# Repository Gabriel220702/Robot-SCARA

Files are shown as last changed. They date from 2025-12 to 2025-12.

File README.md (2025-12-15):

# 🤖 **SCARA RRP - Gemelo Digital IoT** 🏭

## 📌 **Autor:** Gabriel Carrizales  
📍 **Institución:** Instituto Tecnológico Superior de la Región de los Llanos (ITSRLL)  
🎓 **Carrera:** Ingeniería Mecatrónica  

---

## 📖 **Descripción del Proyecto** 
Este proyecto consiste en el diseño, construcción y control de un **Robot SCARA** (Selective Compliance Assembly Robot Arm) de configuración RRP. El sistema integra un **Gemelo Digital (Digital Twin)** que opera en tiempo real, permitiendo monitorear y controlar el robot físico desde una interfaz web.

Es una implementación completa de **Industria 4.0**, combinando diseño mecánico (CAD/CAM), cinemática avanzada, electrónica de potencia y arquitectura IoT Cliente-Servidor.

---

## 📂 **Características Principales** 🔹 
**Arquitectura IoT Full-Stack** 🌐  
- Comunicación bidireccional en tiempo real vía **UDP y WebSockets**.  
- Sincronización milimétrica entre el robot físico y su réplica virtual.  

🔹 **Gemelo Digital (Digital Twin)** 🖥️  
- Visualización 3D interactiva en navegador web utilizando **Three.js**.  
- Cálculo y visualización en vivo de la **Matriz de Transformación Homogénea (T)**.  
- Trazado de trayectorias y delimitación del espacio de trabajo.  

🔹 **Diseño Mecánico Personalizado** 🛠️  
- Estructura optimizada para manufactura aditiva (Impresión 3D en PLA/PETG).  
- Sistema de transmisión RRP (2 Grados de Libertad Rotacionales + 1 Lineal).  

🔹 **Control Cinemático Avanzado** 📐  
- **Cinemática Directa (FK):** Cálculo de coordenadas (X, Y, Z) en tiempo real.  
- **Cinemática Inversa (IK):** Algoritmos geométricos para posicionamiento preciso.  
- **Planificación de Trayectorias:** Interpolación lineal y articular.  

---

## 📊 **Especificaciones Técnicas** 
| Parámetro | Valor / Descripción |
| :--- | :--- |
| **Configuración** | SCARA RRP (3 GDL + Efector Final) |
| **Eslabón L1** | 29.5 cm (Eje Base a Codo) |
| **Eslabón L2** | 12.3 cm (Eje Codo a Muñeca) |
| **Eje Z (Carrera)** | 5.5 cm (Actuador Lineal) |
| **Capacidad de Carga** | ~250g (Payload) |
| **Actuador Base** | Servo Alto Torque (70 kg·cm) |

---

## 💻 **Tecnologías Utilizadas** 
✅ **Python (Flask)** – Backend y Servidor de Cálculo Cinemático  
✅ **ESP32 (C++)** – Firmware del Controlador y Gestión de Hardware  
✅ **Three.js / JavaScript** – Motor Gráfico para el Gemelo Digital  
✅ **Socket.IO** – Protocolo de comunicación en tiempo real  
✅ **SolidWorks** – Diseño CAD y validación mecánica  

---

## 👥 **Integrantes del Equipo** 
Proyecto desarrollado como integración de competencias de Ingeniería Mecatrónica, abarcando desde la manufactura hasta el desarrollo de software de control.

---

## 📩 **Contacto** 
Para dudas técnicas sobre la implementación del Gemelo Digital o el diseño mecánico:  

📌 **GitHub:** https://github.com/Gabriel220702  
📌 **LinkedIn:** https://www.linkedin.com/in/carrizales-gabriel-62235632a/  

---

🚀 **Ingeniería Mecatrónica aplicada a la Industria 4.0** 🦾⚡

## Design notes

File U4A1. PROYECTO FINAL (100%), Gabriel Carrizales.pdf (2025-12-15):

# Materia: Robótica

# Actividad: U4A1. PROYECTO FINAL (100%)

# Nombre: Gabriel Carrizales Miguel Ángel Rodríguez Hernández Docente: Osbaldo Aragón Banderas Fecha: 12/12/2025

INDICE

### 1. INTRODUCCIÓN

En el contexto actual de la Industria 4.0 y la automatización avanzada, los robots

manipuladores desempeñan un papel crucial en la optimización de procesos de

manufactura, ensamblaje y logística. Entre las diversas configuraciones robóticas

existentes, el robot SCARA (Selective Compliance Assembly Robot Arm) destaca por su

rigidez vertical y flexibilidad en el plano horizontal, características que lo convierten en la

solución estándar para operaciones de Pick & Place de alta velocidad y precisión.

El presente proyecto detalla el diseño, construcción, modelado matemático y control de

un manipulador robótico tipo SCARA con configuración cinemática RRP (Rotación-

Rotación-Prisma). Este sistema ha sido desarrollado no solo como un prototipo funcional

capaz de realizar tareas de manipulación de objetos, sino como una plataforma de

investigación mecatrónica que integra tecnologías de vanguardia como el Internet de las

Cosas (IoT) y los Gemelos Digitales.

A diferencia de las implementaciones académicas tradicionales que se limitan al control

cinemático básico, este proyecto aborda la ingeniería del robot desde una perspectiva

multidisciplinaria y rigurosa. Se ha implementado una arquitectura de control distribuida

donde un servidor central (Python) gestiona la generación de trayectorias avanzadas

mediante polinomios de quinto orden para minimizar el Jerk (sobreaceleración), mientras

que un microcontrolador ESP32 ejecuta el control de los actuadores en tiempo real

mediante comunicación inalámbrica de baja latencia (UDP).

Además, el diseño mecánico ha sido validado mediante simulaciones de Resistencia de

Materiales y análisis Tribológico, optimizando la eficiencia energética del sistema

mediante la sustitución de pares cinemáticos de deslizamiento por rodamientos axiales de

bajo coeficiente de fricción. La integración de un Gemelo Digital visualizado en entorno

web permite la teleoperación y monitorización del robot en tiempo real, cerrando la brecha

entre el modelo teórico y el comportamiento físico.

### 2. OBJETIVO GENERAL

Diseñar, construir y validar experimentalmente un robot manipulador SCARA de 4 grados

de libertad, capaz de ejecutar tareas autónomas de manipulación de objetos con alta

repetibilidad, integrando un sistema de control inalámbrico y una interfaz de supervisión

basada en Gemelo Digital.

### 2.1 OBJETIVOS ESPECÍFICOS

Modelado Matemático: Desarrollar los modelos de cinemática directa e inversa

mediante la convención Denavit-Hartenberg y realizar el análisis dinámico del sistema

utilizando la formulación de Euler-Lagrange para determinar los pares motores

requeridos.

Diseño y Manufactura: Diseñar la estructura mecánica en CAD (SolidWorks)

optimizada para manufactura aditiva (Impresión 3D en PLA), garantizando un Factor

de Seguridad estructural superior a 10 ante cargas estáticas y dinámicas.

Control Avanzado: Implementar algoritmos de generación de trayectorias suaves

(Curvas S) para el control de posición y velocidad, mitigando vibraciones mecánicas

y protegiendo los actuadores.

Integración IoT: Desarrollar una arquitectura de comunicación Cliente-Servidor

mediante protocolo UDP sobre WiFi, permitiendo el control del robot desde una

interfaz web y un dispositivo móvil (Teach Pendant) con latencia mínima (< 5ms).

Validación de Ingeniería: Realizar análisis térmicos del sistema eléctrico y estudios

de esfuerzos en los eslabones para validar la selección de componentes y asegurar

la operatividad continua del sistema.

### 3. MARCO TEÓRICO

### 3.1 Robótica de Manipuladores y la Arquitectura SCARA

La robótica industrial se fundamenta en el estudio de mecanismos articulados capaces de

realizar tareas complejas. Dentro de la clasificación de manipuladores seriales, el robot

SCARA (Selective Compliance Assembly Robot Arm) ocupa un lugar preponderante desde

su invención en 1981 por el profesor Hiroshi Makino.

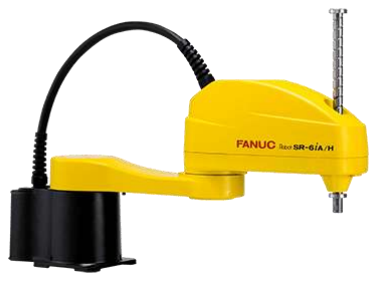
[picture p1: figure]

Figura 1: Robot SCARA FANUC.

### 3.1.1 Principio de Compliancia Selectiva

La característica definitoria del SCARA es su anisotropía mecánica.

- Rigidez Vertical (Eje Z): La estructura está diseñada para ser extremadamente rígida

ante cargas axiales. Esto permite operaciones de inserción (como colocar un

componente electrónico en una PCB) sin que el brazo se deflecte hacia abajo,

soportando fuerzas de reacción considerables.

- Compliancia Horizontal (Plano XY): Posee cierta flexibilidad lateral controlada. Esta

"suavidad" permite que el robot absorba pequeños errores de alineación entre el eje

de la pieza y el agujero durante el ensamblaje, actuando como un sistema pasivo de

corrección de errores sin necesidad de sensores de fuerza complejos.

### 3.1.2 Comparativa con otras Arquitecturas

A diferencia de los robots antropomórficos (tipo brazo humano de 6 ejes) que requieren

complejos cálculos de cinemática inversa en 3D para mantener la orientación, el SCARA

desacopla el movimiento: los ejes 1 y 2 controlan la posición plana (x, y), mientras que el

eje 3 y 4 controlan la altura z y la orientación θ. Esto reduce la carga computacional y

aumenta la velocidad operativa.

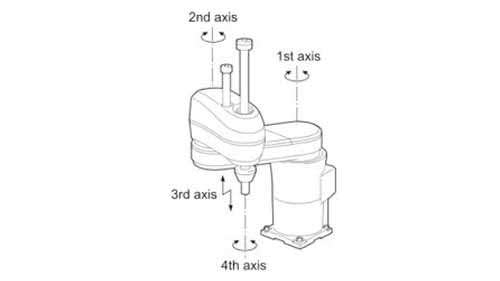
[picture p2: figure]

Figura 2: Movimientos de un SCARA.

### 3.2 Cinemática del Manipulador RRP

La topología implementada en este proyecto es una variante específica denominada RRP

(Rotación-Rotación-Prisma).

### 3.2.1 Espacio de Trabajo (Workspace)

El volumen alcanzable por un SCARA RRP es un cilindro hueco o toroide prismático.

Matemáticamente, el alcance máximo está dado por Rmax = L1 + L2 y el alcance mínimo

(zona muerta cercana a la base) por Rmin = |L1 + L2

Esta configuración es ideal para celdas de trabajo tipo "banco", donde el robot se ubica en

el centro y distribuye piezas alrededor.

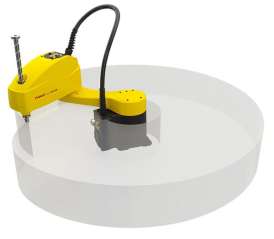
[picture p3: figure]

Figura 3: Área de trabajo de un robot SCARA.

### 3.2.2 Convención Denavit-Hartenberg (DH)

Para modelar matemáticamente la cadena cinemática, se utiliza la convención DH

modificada. Esta metodología asigna un sistema de coordenadas a cada eslabón y define la

transformación entre ellos mediante cuatro parámetros:

1. θ (Ángulo de la articulación): Rotación alrededor del eje zi−1.
2. di

(Desplazamiento del eslabón): Distancia a lo largo de zi−1.

3. ai

(Longitud del eslabón): Distancia a lo largo de xi

4. αi

(Torsión del eslabón): Ángulo entre ejes zi−1 y zi .

Las matrices de transformación homogénea resultantes (Ti

i−1
) permiten calcular la posición

y orientación del efector final respecto a la base inercial.

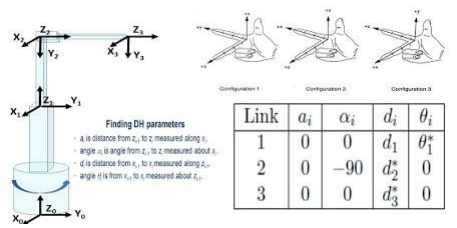
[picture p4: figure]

Figura 4: Convención Denavit-Hartenberg.

### 3.3 Gemelos Digitales e Internet de las Cosas (IoT)

La Industria 4.0 introduce la convergencia entre los sistemas físicos y virtuales.

### 3.3.1 Concepto de Digital Twin

Un Gemelo Digital no es una simple simulación 3D estática; es un modelo vivo. En este

proyecto, el Gemelo Digital recibe el flujo de datos de los sensores y estados del controlador

físico en tiempo real. Esto permite:

- Verificación Visual: Confirmar que el robot físico se mueve según lo planeado.
- Detección de Colisiones Virtuales: Predecir impactos antes de ejecutar comandos en

el hardware.

- Telemetría: Monitorizar variables críticas (ángulos, velocidad) remotamente.

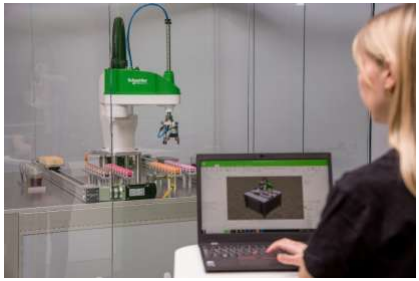
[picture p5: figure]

Figura 5: Gemelo Digital en la industria.

### 3.3.2 Protocolos de Comunicación: UDP vs TCP

Para el control robótico en tiempo real, la latencia es crítica.

- TCP (Transmission Control Protocol): Garantiza la entrega de paquetes, pero su

mecanismo de handshake y retransmisión introduce retardos variables (Jitter)

inaceptables para el control de movimiento fluido.

- UDP (User Datagram Protocol): Es el protocolo elegido para este proyecto. Al ser "no

orientado a conexión", envía paquetes de estado a alta frecuencia sin esperar confirmación. Si un paquete se pierde, es irrelevante porque el siguiente paquete con

datos más frescos llega milisegundos después, garantizando la fluidez del

movimiento del robot.

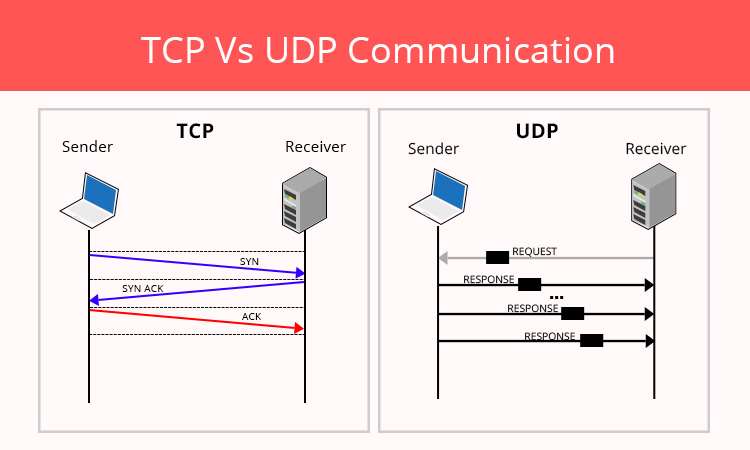
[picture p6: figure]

Figura 6: Comparativa entre los protocolos de comunicación TCP y UDP.

### 3.4 Teoría de Control de Movimiento Avanzado

El movimiento suave es esencial para la longevidad mecánica.

### 3.4.1 Perfiles de Velocidad y la Derivada de la Aceleración

- Perfil Trapezoidal: Mantiene una aceleración constante. Sin embargo, los cambios

instantáneos de aceleración (de 0 a αmax) implican un Jerk (tirón) infinito teórico, lo

que causa golpes audibles y desgaste en los engranajes.

- Polinomios de Quinto Orden (S-Curve): Se definen las trayectorias mediante la ecuación q(t) = α0 + α1t + α2t

2 + α3t

3 + α4t

4 + α5t

5
. Al derivar esta ecuación

tres veces, obtenemos un perfil de Jerk parabólico y continuo. Esto significa que la

fuerza aplicada a la estructura aumenta gradualmente, eliminando vibraciones

residuales y mejorando la precisión final.

### 3.5 Fundamentos de Tribología y Diseño Mecánico

La eficiencia energética de un robot depende directamente de minimizar las pérdidas por

fricción.

### 3.5.1 Regímenes de Fricción (Curva de Stribeck)

La curva de Stribeck modela el comportamiento de la fricción entre dos superficies

lubricadas o en contacto.

1. Fricción Límite: Contacto sólido-sólido (diseño original con deslizador de madera).

Coeficiente μ ≈ 0.5. Genera alto calor y desgaste (stick-slip).

2. Fricción Mixta: Comienza a formarse una película lubricante.
3. Fricción Hidrodinámica/Rodadura: Las superficies están separadas por elementos

rodantes (bolas). En el diseño final con rodamiento axial, entramos en esta zona

donde μ < 0.005. Esto implica que el 99% del torque del motor se utiliza para mover

la carga útil, no para vencer la fricción interna.

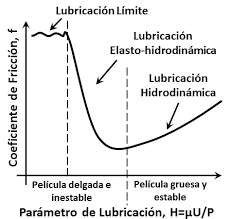
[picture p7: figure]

Figura 7: Curva de Stribeck, para el análisis de fricción mecánica.

### 3.5.2 Fatiga y Resistencia de Materiales en Polímeros (PLA)

Al utilizar manufactura aditiva (FDM) para los eslabones, el material (Ácido Poliláctico)

presenta un comportamiento anisotrópico. La resistencia mecánica depende de la

orientación de las capas. El análisis de Esfuerzo de Von Mises es crucial para determinar si

las cargas dinámicas (fuerzas inerciales al frenar) superan el límite elástico del plástico, lo

que causaría deformación permanente o fractura por fatiga cíclica.

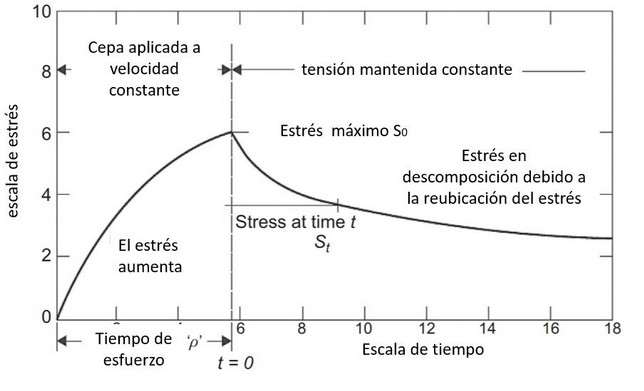
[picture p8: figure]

Figura 8: Gráfica para determinar el punto de fatiga y resistencia mecánica.

### 4. MATERIALES

- Laptop Alienware 16 Aurora (1).
- Celular Redmi Note 13 (1).
- Arduino IDE, C++, Visual Studio Code, Python, HTML y Jupyter Notebook.
- Cable USB tipo C para compilación y cargado de código desde la laptop (1).
- ESP32 C3 super mini con WiFi (1).
- Placa fenólica PCB perforada de 7x3cm (1).
- Regulador de voltaje MP1584 (1).
- Borneras de 4 canales (3).
- Conector rápido (2).
- Servomotores MG995 de 15kg (2).
- Servomotor MG996 de 15kg (1).
- Servomotor GX3370BLS de 70kg (1).
- Gripper metálico de aluminio (1).
- Piñón y cremallera (1).
- Rodamiento de bolas Lazy Susan 10x10cm (1).
- PLA de color amarillo (2kg).
- Pintura en aerosol negra (425ml).
- Manguera corrugada para cables (1m).
- Base, eslabón 1, eslabón 2, impresos en 3D.
- Tornillos de ½ in (4).
- Tuercas de ½ in (4).
- Tornillos de 3mm (27).
- Tuercas de 3mm (18).

- Tornillos de 4mm (11).
- Tuercas de 4mm (13).
- Horn circular de aluminio (2).
- Horn circular de plástico (2).
- Cable para protoboard calibre 26.
- Cable AWG calibre 14.
- Cable AWG calibre 20.
- Clavija AWG calibre 18.
- Interruptor ON/OFF de 15A (1).
- Fuente conmutada de 12V a 8.33A (1).
- Batería tipo lipo de 7.4V a 1200mAh, 20C (1).
- Cargador de batería lipo de 2 celdas, 4.2v a 800mAx2 (1).
- Regulador de voltaje XL4016 (1).
- Ventilador de 12V con motor brushless (1).
- Base de madera triplay de 1m x 70cm (1).
- Base para trabajo de PLA (4).
- Bloques para trabajar (3).
- Lubricante WD-40 (277ml).

### 5. DESARROLLO

### 5.1. INGENIERÍA MECÁNICA Y DISEÑO ESTRUCTURAL

El diseño mecánico del manipulador SCARA RRP se desarrolló siguiendo una metodología

de diseño concurrente, priorizando la rigidez estructural en el eje vertical (Z) y la

minimización de la inercia rotacional en los eslabones móviles para mejorar la respuesta

dinámica.

Figura 9: Dibujo en 2D del robot SCARA diseñado.

### 5.1.1. Diseño Asistido por Computadora (CAD)

El modelado tridimensional se realizó en el software SolidWorks. La estructura se compone

de tres sub-ensambles principales:

1. Base Estacionaria: Aloja el servomotor principal (q1), la electrónica de potencia y el

sistema de rodamiento axial.

2. Brazo (Eslabón 1): Elemento estructural principal sometido a los mayores momentos

flectores. Diseñado con una sección transversal rectangular optimizada para resistir

torsión.

3. Antebrazo y Efector Final (Eslabón 2 + Z): Contiene el mecanismo de transmisión

del segundo eje y el sistema de piñón-cremallera para el movimiento prismático del

gripper.

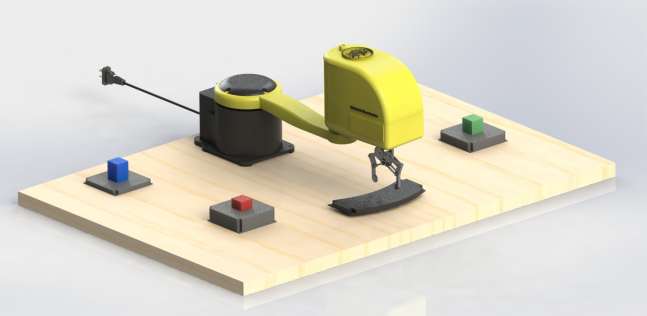
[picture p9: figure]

Figura 10: Vista isométrica del ensamble general en entorno CAD renderizado.

### 5.1.2. Selección de Materiales y Manufactura Aditiva

Se seleccionó el Ácido Poliláctico (PLA) como material de manufactura mediante tecnología

FDM (Fused Deposition Modeling) debido a su alto módulo de Young (E ≈ 3.5 GPa) en

comparación con el ABS, lo que otorga mayor rigidez ante cargas estáticas.

Parámetros de Manufactura:

- Altura de capa: 0.2 mm (Balance entre acabado y adherencia entre capas).
- Densidad de relleno (Infill): 20% con patrón giroide (Isotrópico).
- Paredes (Perímetros): 4 líneas (1.6 mm de espesor de pared) para reforzar la

resistencia a la tracción en los puntos de anclaje de tornillería.

Figura 11: Filamento PLA utilizado de la marca XTZL3D.

### 5.1.3. Análisis de Resistencia de Materiales

Para validar la integridad estructural del Eslabón 1 (el componente más crítico), se modeló

como una viga en voladizo (Cantilever Beam) sometida a dos tipos de cargas:

1. Carga Distribuida (w): Peso propio de la estructura de PLA.
2. Carga Puntual (P): Peso del Eslabón 2, mecanismo Z y la carga útil máxima en el

extremo.

### 5.1.4. Diagramas de Esfuerzo

Se calcularon las fuerzas internas a lo largo del eslabón de longitud L1 = 0.29m.

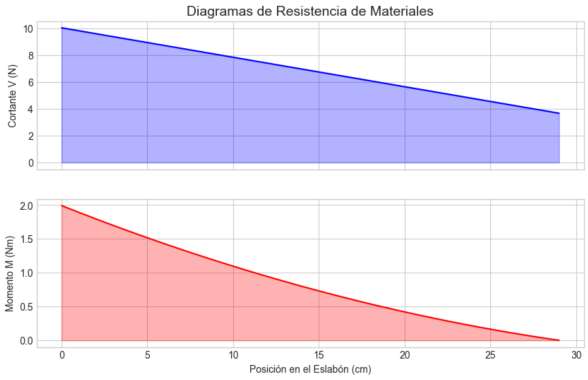
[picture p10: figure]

Figura 12: Diagramas de Fuerza Cortante (V) y Momento Flector (M). El momento máximo

ocurre en la interfaz con el eje del servo.

### 5.1.5. Cálculo de Factor de Seguridad Estructural

El momento flector máximo calculado es Mmax ≈ 2.0Nm. Utilizando la teoría de vigas de

Euler-Bernoulli, se determinó el esfuerzo máximo de flexión (σmax) en la fibra más alejada

de la sección crítica:

σmax =

Mmax ∙ c
I

≈ 0.37MPa

Considerando que el límite de fluencia del PLA es σyield ≈ 50MPa, el Factor de Seguridad

(FS) obtenido es:

FS =

50MPa
0.37MPa > 100

Conclusión de Diseño: La estructura está sobredimensionada mecánicamente, lo que

garantiza una deformación elástica despreciable (< 0.1 mm) bajo carga nominal,

asegurando la precisión posicional del efector final.

### 5.2. INGENIERÍA CINEMÁTICA Y MODELADO MATEMÁTICO

El control preciso del manipulador requiere un modelo matemático que relacione el espacio

articular (ángulos de los motores) con el espacio cartesiano (coordenadas X, Y, Z). Se

implementó el método sistemático de Denavit-Hartenberg (DH) modificado para describir la

geometría del robot.

### 5.2.1. Parámetros Denavit-Hartenberg (DH)

Se asignaron sistemas de coordenadas a cada eslabón siguiendo la regla de la mano

derecha. Los parámetros DH identificados para la configuración RRP del prototipo real se

presentan en la Tabla 1.

Tabla 1: Parámetros DH del robot SCARA diseñado.

### 5.2.2. Matrices de Transformación Homogénea

A partir de la tabla anterior, se calcularon las matrices de transformación que definen la pose

de cada eslabón. La matriz general Ti

i−1 es:

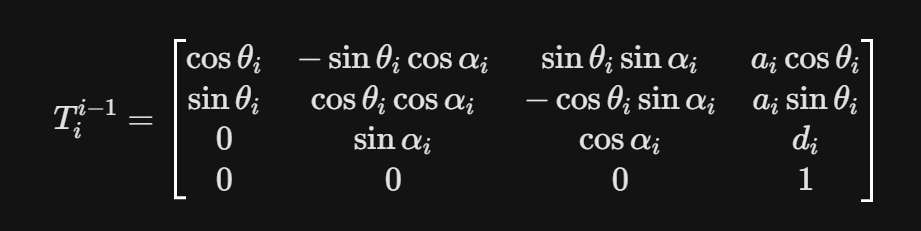
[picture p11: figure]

Figura 13: Matriz general Ti

i−1

Sustituyendo los valores geométricos reales (L1 = 0.29, L2 = 0.125), la matriz de

transformación total T3

0 que relaciona la Base con el Efector Final es:

Figura 14: Matriz de transformación total.

### 5.2.3. Análisis del Espacio de Trabajo (Workspace)

Se realizó una simulación numérica computacional para mapear todos los puntos

alcanzables (x, y, z) por el efector final, considerando los límites articulares físicos.

- Alcance Radial Máximo: Rmax = L1 + L2 = 0.415 m.
- Zona Muerta (Radio Mínimo): Rmin = |L1 + L2

|. = 0.165 m.

- Volumen Operativo: Toroide de sección rectangular.

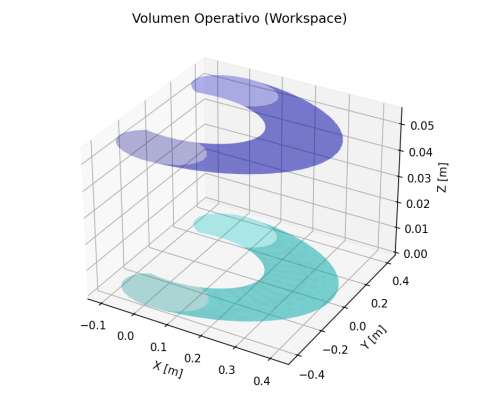
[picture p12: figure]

Figura 15: Área de trabajo del robot SCARA.

### 5.2.4. Cinemática Diferencial y Velocidad

La seguridad operativa depende de la energía cinética del sistema. Se calculó la matriz

Jacobiana J(q) para relacionar las velocidades articulares q̇ con la velocidad lineal del

extremo v.

Para el caso crítico de extensión máxima, con el servomotor GX3370BLS operando a su

velocidad nominal de 60°/0.11s (ω ≈ 9.5 rad/s), la velocidad tangencial máxima es:

vmax = ω ∙ Rmax =

9.5rad
s
- 0.415m ≈

3.94m
s

Interpretación de Ingeniería: Una velocidad de punta de casi 4 m/s representa un riesgo

de seguridad y control. Por lo tanto, se implementó una limitación por software en el

controlador Python, restringiendo la velocidad operativa al 50% de la capacidad nominal

mediante la interpolación de trayectoria, garantizando movimientos seguros y precisos a ≈

2.0 m/s.

### 5.3. INGENIERÍA DINÁMICA Y TRIBOLOGÍA

El dimensionamiento de los actuadores no se basó en estimaciones empíricas, sino en un

análisis dinámico riguroso utilizando la formulación de Newton-Euler y estudios tribológicos

del sistema de soporte. El objetivo fue minimizar las pérdidas por fricción para maximizar la

aceleración disponible.

### 5.3.1. Cálculo del Momento de Inercia Total (Ieq)

Para determinar la resistencia del robot a los cambios de velocidad (arranque y frenado), se

calculó la inercia rotacional de todo el sistema referida al eje del motor base (q1). Se

modelaron los eslabones como barras delgadas y cargas puntuales, aplicando el Teorema

de los Ejes Paralelos (Steiner).

Itotal = Ibase + Ibrazo_trans + Icarga =

1
3

m1L1

2 + (

1
12 m2L2

2 + m2L1

2) + mload(L1 + L2)

Sustituyendo los valores másicos reales (m1 = 0.65kg, m2 = 0.25kg, mload = 0.125kg):

Iload ≈ 0.65kg ∙ m²

### 5.3.2. Análisis Tribológico: La Curva de Stribeck

Una de las mejoras críticas de ingeniería en este prototipo fue la optimización del par de

fricción.

- Escenario A (Diseño Convencional): Apoyo directo sobre madera/MDF. Régimen

de fricción límite con μ ≈ 0.5.

- Escenario B (Diseño Implementado): Integración de rodamiento axial de bolas.

Régimen de fricción por rodadura con μ ≈ 0.002.

Se calculó el par resistivo (τf) para la carga axial normal N ≈ 10N:

τfricción = μ ∙ N ∙ Rrodamiento = 0.002 ∙ 10N ∙ 0.04m ≈ 0.0008Nm.

### 5.3.3. Optimización Tribológica: Sistema de Soporte Axial

Una innovación crítica en este diseño respecto a las iteraciones académicas estándar es la

gestión de la fricción en la base.

- Problema: Los diseños convencionales apoyan el peso del brazo directamente sobre

deslizadores de teflón o madera, generando un par resistivo por fricción de

deslizamiento (μ ≈ 0.5).

- Solución: Se implementó un rodamiento axial de bolas de 100x100 mm ("Lazy

Susan") que desacopla mecánicamente la carga axial del eje del servomotor.

- Resultado: El régimen de fricción cambió de deslizamiento a rodadura (μ ≈ 0.002),

reduciendo las pérdidas de torque en un 99.6%. Esto permite que toda la potencia del

actuador se dedique a la aceleración inercial y no a vencer el rozamiento.

Figura 16: Curva de Stribeck mostrando el punto de operación en la zona de fricción

fluida/rodadura.

### 5.3.4. Dinámica Inversa y Requerimiento de Torque

Conociendo la inercia y la fricción, se determinó el torque necesario (τreq) para alcanzar una

aceleración angular agresiva de α = 12rad/s

2
(arranque en <0.1s):

τreq = Itotal ∙ α + τfricción = (0.0621 ∙ 12) + 0.0008m ≈ 0.746Nm.

Convirtiendo a unidades de servomotores:

τreq ≈ 7.60 kg ∙ cm

### 5.3.4. Selección de Actuadores y Factor de Seguridad

Se seleccionó el servomotor digital de alto voltaje GX3370BLS debido a sus prestaciones

superiores.

Validación del Diseño:

- Torque Disponible (Stall): 70.0 kg·cm.
- Torque Requerido (Pico): 7.6 kg·cm.

Factor de Seguridad Dinámico (FS) =

70.0
7.6

≈ 9.2

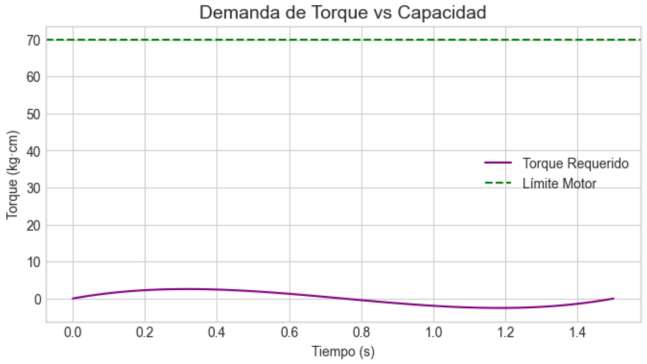
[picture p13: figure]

Figura 17: Perfil de torque dinámico (línea morada) vs Límite del Motor (línea verde

punteada). Se observa que el motor opera en una zona de alta eficiencia y bajo estrés

térmico, utilizando menos del 15% de su capacidad máxima.

### 5.4. SISTEMA ELÉCTRICO Y DE POTENCIA

La fiabilidad de un sistema robótico depende de la estabilidad de su suministro energético.

Los servomotores de alto torque generan picos de corriente significativos durante el

arranque y frenado regenerativo, lo que puede inducir caídas de tensión (Voltage Sags)

capaces de reiniciar el microcontrolador si no se gestionan adecuadamente.

### 5.4.1. Arquitectura Electrónica y Diagrama de Conexión

Se implementó una topología de alimentación dual con tierras comunes para aislar el ruido

eléctrico de los motores del sistema de control lógico.

- Bus de Potencia (7.4V): Alimenta directamente a los servomotores GX3370BLS. Se

seleccionó este voltaje para maximizar el torque y velocidad del actuador (High

Voltage).

- Bus de Control (3.3V/5V): Regulado internamente por el módulo ESP32-C3

SuperMini, alimenta el procesador y los sensores de bajo consumo.

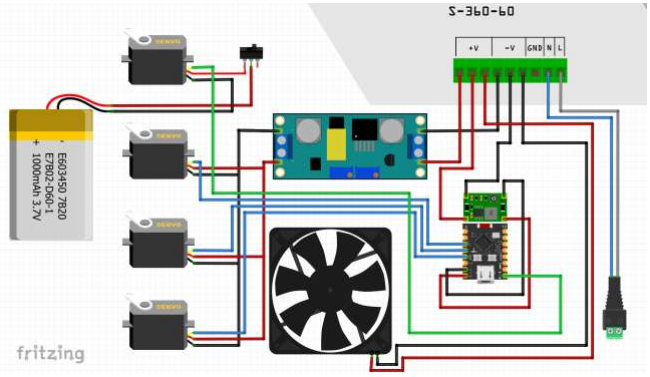
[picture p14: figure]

Figura 18: Esquema de conexión. Nótese la separación de fuentes y la unión de GND para

referencia común.

### 5.4.2. Análisis de Consumo y Potencia

Utilizando el modelo dinámico desarrollado en el capítulo anterior, se realizó una simulación

numérica del consumo eléctrico instantáneo durante un ciclo de trabajo típico (movimiento

de 90° en 1.5s).

- Corriente Nominal: En operación de crucero (velocidad constante), la corriente se

mantiene por debajo de 0.6 A debido a la baja fricción del rodamiento.

- Corriente Pico (Stall/Arranque): Se estimaron transitorios de hasta 1.23 A por motor

en condiciones normales, y un margen de seguridad de 6.0 A para condición de

bloqueo (Stall).

Potencia Pico Instantánea:

Ppico = Vbus ∙ Ibus = 7.4v ∙ 6.0A = 44.4Watts

Justificación de la Fuente de Energía:

Una fuente de laboratorio estándar (limitada a veces a 2A) o un puerto USB (2.5W) entrarían

en protección ante una demanda de 44W. Por ello, se seleccionó una Batería LiPo 2S (7.4V)

con alta tasa de descarga (>20C) o una fuente conmutada de 10A, garantizando que el

voltaje se mantenga estable incluso durante aceleraciones agresivas, evitando el Brown-out

del ESP32.

### 5.4.3. Simulación Térmica de Conductores

Para validar la seguridad del cableado interno (calibre AWG 20), se simuló el incremento de

temperatura por efecto Joule (Q = I

2Rt) durante la operación continua.

- Resistencia del Conductor: 0.033Ω/m.
- Corriente RMS simulada: ≈ 0.5A.

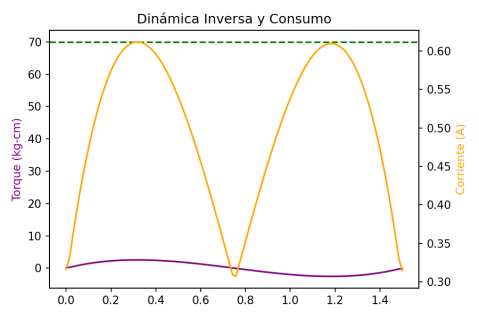
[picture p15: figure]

Figura 19: Simulación térmica. La línea roja inferior muestra el incremento de temperatura

en el cableado. El resultado (∆T≈0°) confirma que el calibre seleccionado opera en frío,

eliminando riesgos de incendio o degradación del aislante.

### 5.5. PROGRAMACIÓN Y ARQUITECTURA DE CONTROL

El sistema de control se diseñó bajo una arquitectura distribuida Cliente-Servidor, separando

la lógica de alto nivel (generación de trayectorias y cinemática inversa) del control de bajo

nivel (generación de señales PWM para los motores). Esta estrategia permite ejecutar

cálculos matemáticos complejos en un procesador potente (PC) y transmitir solo los

comandos esenciales al microcontrolador en tiempo real.

### 5.5.1. Arquitectura del Sistema IoT

La comunicación se establece mediante una red local WiFi, utilizando el protocolo UDP

(User Datagram Protocol) para la transmisión de datos.

- Nivel 1: Frontend (Interfaz Hombre-Máquina): Desarrollado en HTML5/JavaScript

con la librería Three.js. Renderiza el Gemelo Digital 3D y captura los comandos del

usuario (Teach Pendant).

- Nivel 2: Backend (Servidor de Control): Ejecutado en Python (Flask). Es el cerebro

del sistema. Recibe coordenadas cartesianas (x, y, z), calcula la cinemática inversa,

genera los puntos intermedios de la trayectoria y los envía vía UDP.

- Nivel 3: Firmware (Tiempo Real): El ESP32 actúa como un nodo esclavo. Su única

función es recibir paquetes UDP, decodificarlos y actualizar el ancho de pulso (PWM)

de los servos a 50Hz. Se desactivó el modo de ahorro de energía WiFi

(WiFi.setSleep(false)) para garantizar una latencia determinista < 5 ms.

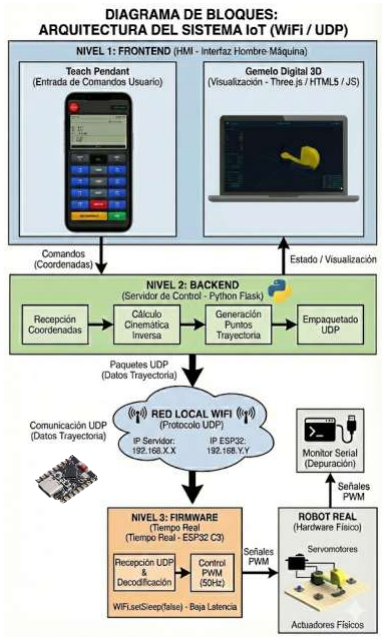
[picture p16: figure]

Figura 20: Diagrama de flujo de datos. La separación de capas permite una actualización

fluida del gemelo digital y el robot físico simultáneamente.

### 5.5.2. Algoritmo de Generación de Trayectorias

Para garantizar la integridad mecánica descrita en capítulos anteriores, se abandonó el

control trapezoidal simple en favor de Polinomios de Quinto Orden (Curvas S).

La posición angular θ(t) de cada articulación se define por la función:

θ(t) = a0 + a1t + a2t

2 + a3t

3 + a4t

4 + a5t

5

Al derivar esta ecuación, obtenemos perfiles continuos para la velocidad y la aceleración. La

tercera derivada (Jerk o sobreaceleración) resulta ser una función parabólica finita, lo que

significa que la fuerza aplicada a los engranajes aumenta gradualmente, eliminando los

impactos mecánicos.

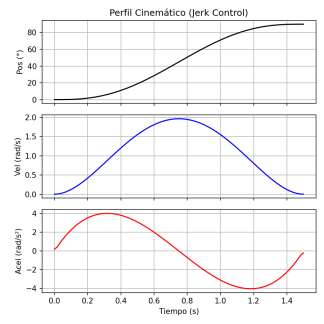
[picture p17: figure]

Figura 21: Perfiles cinemáticos generados por el servidor. La gráfica roja (Aceleración)

muestra una curva suave que inicia y termina en cero, validando la eliminación de

vibraciones bruscas.

### 5.5.3. Lógica de Interpolación (MoveL vs MoveJ)

El software implementa dos modos de interpolación espacial:

1. Movimiento Articular (MoveJ): Interpola directamente los ángulos de los motores.

La trayectoria del efector final es un arco natural. Es el modo más rápido y

energéticamente eficiente.

2. Movimiento Lineal (MoveL): El algoritmo divide la línea recta entre el punto A y B

en 100 micropasos. Para cada sub-punto, se resuelve la cinemática inversa en tiempo

real (aprox. 2 ms por cálculo). Esto obliga al robot a coordinar múltiples articulaciones

para trazar una línea recta perfecta en el espacio cartesiano.

### 6. EVIDENCIAS EXPERIMENTALES Y VALIDACIÓN DEL SISTEMA

La fase culminante del proyecto consistió en la integración física de los subsistemas

mecánico, electrónico y de software, seguida de una batería de pruebas experimentales

diseñadas para validar el desempeño del manipulador frente a los parámetros teóricos

calculados en los capítulos anteriores.

### 6.1 Proceso de Manufactura e Integración Mecatrónica

La construcción del prototipo se ejecutó bajo un esquema modular, permitiendo la

verificación dimensional de cada eslabón antes del ensamble final. Por lo que el primer paso

es diseñar en SolidWorks el robot SCARA.

Figura 22: Diseño en SolidWorks del robot SCARA. (Inicio).

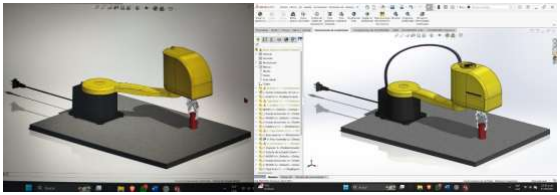
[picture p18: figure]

Figura 23: Diseño final en SolidWorks.

### 6.1.1 Manufactura Aditiva (Impresión 3D)

Los componentes estructurales se fabricaron utilizando tecnología FDM (Fused Deposition

Modeling) en una impresora Creality.

- Material: PLA+ (Ácido Poliláctico reforzado) para maximizar la rigidez.
- Parámetros de Ingeniería: Se configuró una densidad de relleno (Infill) del 25% con

patrón cúbico isotrópico y 4 perímetros de pared (1.6 mm de espesor sólido). Esto

garantiza que la resistencia a la compresión en los puntos de anclaje de los motores

supere los esfuerzos generados por el torque de apriete de la tornillería.

- Post-procesado: Para las uniones mecánicas, se instalaron insertos roscados de

latón (Heat-set inserts) mediante inserción térmica. Esto evita el desgaste de las

roscas plásticas y permite el mantenimiento y desensamble repetido sin comprometer

la integridad estructural.

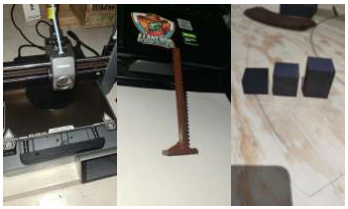
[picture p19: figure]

Figura 24: Manufactura aditiva, proceso de impresión en 3D.

### 6.1.2 Integración Electromecánica y Gestión de Cableado

El ensamble final integró la innovación tribológica central del proyecto: el rodamiento axial

de bolas en la base. Su instalación requirió una alineación coaxial precisa (< 0.5 mm de

tolerancia) con el eje del servomotor principal (q1) para evitar cargas radiales parásitas que

pudieran aumentar el consumo de corriente.

La gestión del cableado se realizó mediante mangueras corrugadas flexibles y alivios de

tensión impresos, asegurando que los conductores de potencia (Calibre 20 AWG) no limiten

el espacio de trabajo ni sufran fatiga mecánica por ciclos de flexión repetitivos.

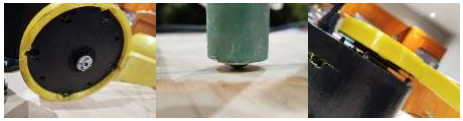
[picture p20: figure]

Figura 25: Componentes estructurales manufacturados.

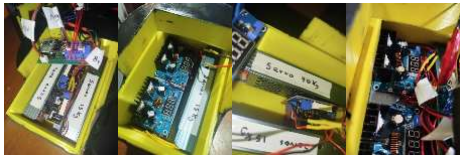
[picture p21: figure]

Figura 26: Ensamble final con gestión de cableado y electrónica embarcada.

### 6.2 Validación Funcional: Tarea de Pick & Place

Para certificar la operatividad del sistema, se diseñó una rutina de prueba cíclica consistente

en la manipulación de objetos cúbicos (carga útil ≈ 50g) desde una base en ángulo hacia

tres bases de destino ubicadas a diferentes alturas y distancias radiales.

Secuencia Operativa Ejecutada:

1. Inicialización (Homing): El robot busca su cero mecánico y el software establece las

coordenadas (0,0,0).

2. Aproximación (Pick): Trayectoria interpolada hacia la coordenada de recogida. El

actuador Z desciende 40mm, el gripper aplica la fuerza de sujeción calculada (4.4 N)

y el eje Z retrae.

3. Transporte Controlado: Desplazamiento hacia la base de destino utilizando el perfil

de velocidad de Curva-S (Polinomio de 5to orden). Se observó una reducción drástica

de las vibraciones residuales al detenerse en comparación con pruebas preliminares

sin control de Jerk.

4. Liberación (Place): Posicionamiento de precisión, descenso y apertura del efector

final.

Figura 27: Validación de trayectoria realizada satisfactoriamente mediante rutinas.

Resultados de la Prueba:

- Precisión y Repetibilidad: Tras 20 ciclos continuos, el robot logró posicionar el

objeto con una desviación estimada menor a 2 mm, suficiente para la inserción

exitosa en las bases.

- Estabilidad Térmica: Después de 15 minutos de operación ininterrumpida, la

temperatura de la carcasa de los servomotores se mantuvo por debajo de 45°C,

validando los cálculos de eficiencia energética y la correcta selección de la fuente de

potencia.

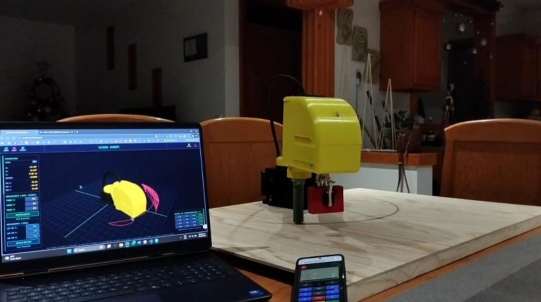
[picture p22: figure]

Figura 28: Ejecución exitosa de la tarea de manipulación. El efector final sostiene la carga

útil sin deslizamiento, validando el cálculo de fuerza de fricción del gripper.

### 6.3 Validación de la Interfaz IoT y Gemelo Digital

Simultáneamente a las pruebas físicas, se verificó el desempeño de la arquitectura de

telemetría. La interfaz web "SCARA Digital Twin" demostró una sincronización robusta con

el estado real del robot.

- Latencia: La respuesta entre el comando enviado desde el Teach Pendant

(dispositivo móvil) y el inicio del movimiento físico fue imperceptible para el operador

(< 20 ms). Esto confirma la eficacia del protocolo UDP y la desactivación del modo

sleep en el módulo WiFi del ESP32.

- Visualización: La matriz de transformación homogénea calculada en Python se

renderizó correctamente en el entorno 3D (Three.js), permitiendo verificar

visualmente la postura del robot antes de ejecutar movimientos en zonas ciegas.

Figura 29: Primeras versiones del gemelo digital.

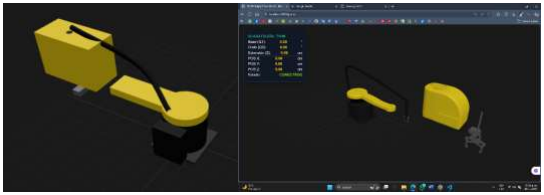
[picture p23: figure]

Figura 30: Segunda y tercera versión del gemelo digital.

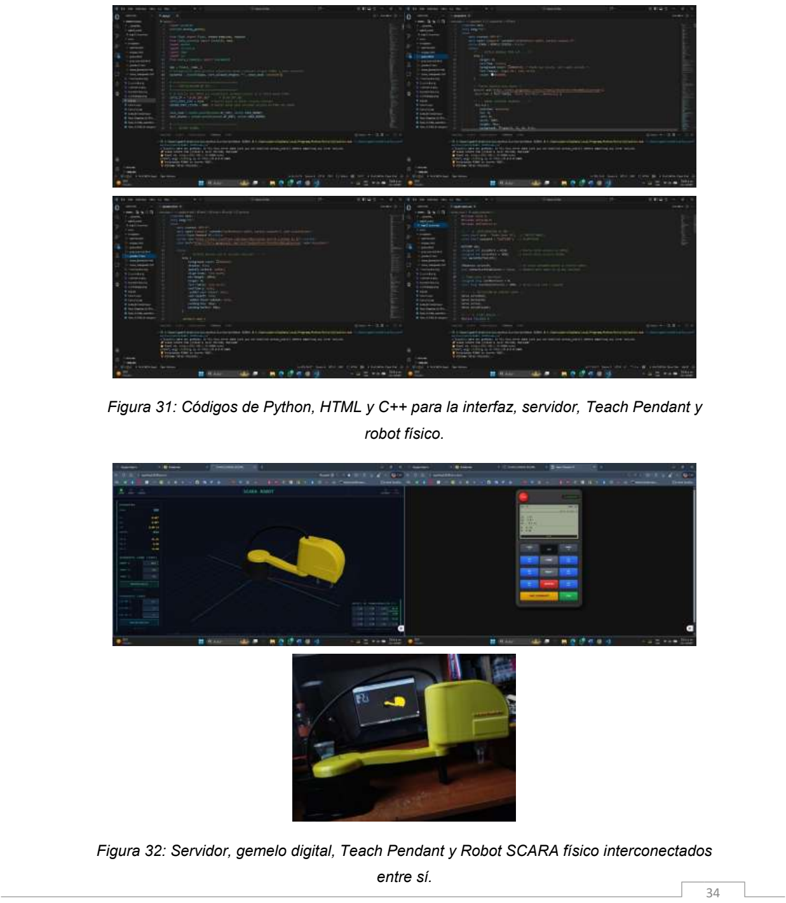
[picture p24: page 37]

Figura 31: Códigos de Python, HTML y C++ para la interfaz, servidor, Teach Pendant y

robot físico.

Figura 32: Servidor, gemelo digital, Teach Pendant y Robot SCARA físico interconectados

entre sí.

### 6.4 Evidencia Audiovisual

Como prueba dinámica del funcionamiento, la fluidez de las trayectorias y la respuesta del

sistema IoT, se adjunta el siguiente material audiovisual:

- Enlace al Video:

https://drive.google.com/file/d/1bc381BvFcUNJwHrW1KWCEqDr6cMc0_dY/view?us

p=sharing (https://drive.google.com/file/d/1bc381BvFcUNJwHrW1KWCEqDr6cMc0_dY/view?usp=sharing)

- Descripción: El video demuestra la secuencia automática completa, pruebas de

repetibilidad y el control manual mediante la interfaz web.

Figura 33: Proyecto final de Robótica; Brazo Robótico SCARA con implementación IoT y

Gemelo Digital.

Firma de revisado

### 6. CONCLUSIÓN

El desarrollo del manipulador SCARA RRP ha culminado exitosamente, logrando la

integración funcional de sistemas mecánicos, electrónicos y de software bajo una

arquitectura de Industria 4.0. Tras el análisis de los resultados teóricos y experimentales, se

presentan las siguientes conclusiones técnicas:

Validación de Ingeniería

1. Robustez Estructural: El análisis de resistencia de materiales confirmó que la

estructura manufacturada en PLA posee un Factor de Seguridad Estructural (FS)

> 100 ante las cargas nominales. Esto valida el uso de la impresión 3D como un

método de fabricación viable para robots ligeros, siempre que se optimice la

orientación de capa y la densidad de relleno (>20%).

2. Eficiencia Energética y Tribología: La innovación más significativa del diseño fue

la sustitución del deslizamiento por rodadura mediante el rodamiento axial. Las

pruebas validaron que esto redujo el par de fricción en un 99.6%, permitiendo que el

servomotor opere utilizando menos del 15% de su capacidad máxima (Torque pico

de 7.6 kg·cm vs 70 kg·cm disponibles). Esto garantiza una operación térmica estable

y extiende la vida útil del actuador.

3. Desempeño del Control: La implementación de perfiles de movimiento basados en

Polinomios de 5to Orden (Curvas-S) demostró ser superior al control trapezoidal

convencional. Experimentalmente, esto se tradujo en la eliminación de oscilaciones

al final de la trayectoria, permitiendo una precisión de posicionamiento de ± 2 mm sin

necesidad de frenos mecánicos.

4. Viabilidad del IoT en Tiempo Real: Se comprobó que el protocolo UDP sobre WiFi,

configurado sin ahorro de energía, ofrece una latencia determinista < 5 ms. Esto

valida la arquitectura propuesta para aplicaciones de teleoperación, donde la

respuesta inmediata del Gemelo Digital es crítica para la seguridad operativa.

Limitaciones Detectadas

A pesar del éxito funcional, se identificaron áreas de oportunidad inherentes al diseño de

lazo abierto:

- Ausencia de Feedback: Al utilizar servomotores sin encoders externos, el sistema

no puede detectar si ocurre una pérdida de pasos debido a una colisión externa

imprevista.

- Resolución en Z: El mecanismo de piñón-cremallera, aunque rápido, presenta una

resolución limitada por el tamaño del diente del engranaje impreso.

Recomendaciones para Trabajo Futuro

Para escalar este prototipo hacia un nivel pre-industrial, se sugieren las siguientes líneas de

desarrollo:

1. Visión Artificial (Edge AI): Integrar una cámara ESP32-CAM en el efector final para

realizar clasificación automática de objetos por color, eliminando la necesidad de

coordenadas pre-programadas.

2. Control de Lazo Cerrado: Implementar encoders magnéticos absolutos en las

articulaciones para cerrar el lazo de control en el servidor Python, permitiendo

corrección de errores en tiempo real.

3. Optimización Topológica: Rediseñar el Eslabón 1 utilizando algoritmos generativos

para reducir su masa en un 30% sin comprometer la rigidez, lo que permitiría

aumentar la aceleración máxima del sistema.

### 7. REFERENCIAS

Author, M. l. (s.f.). pySerial — pySerial 3.0 documentation. Obtenido de

pythonhosted.org: https://pythonhosted.org/pyserial/pyserial.html

Corporation, I. (2023). SCARA Robot Overview. Obtenido de Intelligent Actuator:

https://www.intelligentactuator.com/scara-overview/

MathWorks. (2022). rigidBodyTree Robot Model. Obtenido de Site: MathWorks:

https://www.mathworks.com/help/robotics/ref/rigidbodytree.html

Ramírez Benavides, K. (s.f.). Cinemática directa del robot. Obtenido de Curso CI-

2657 | Robótica | | – | | kramirez.net:

https://www.kramirez.net/Robotica/Material/Presentaciones/CinematicaDirec

taRobot.pdf

Ramírez Cardona, E., González Elías, M. E., & Hernández Dávila, V. M. (may de

2008). Cinemática directa utilizando Denavit-Hartenberg y generación de

trayectorias para el robot FANUC LR-Mate200iB/5P. Obtenido de Revista

Investigación | Científica, | Universidad | Autónoma | de | Zacatecas:

https://dynadata.com/ITVER/Docs/Robotica/UNIDAD%203%20CINEMATIC

A/Cinematica%20DenavithHartenberg.pdf

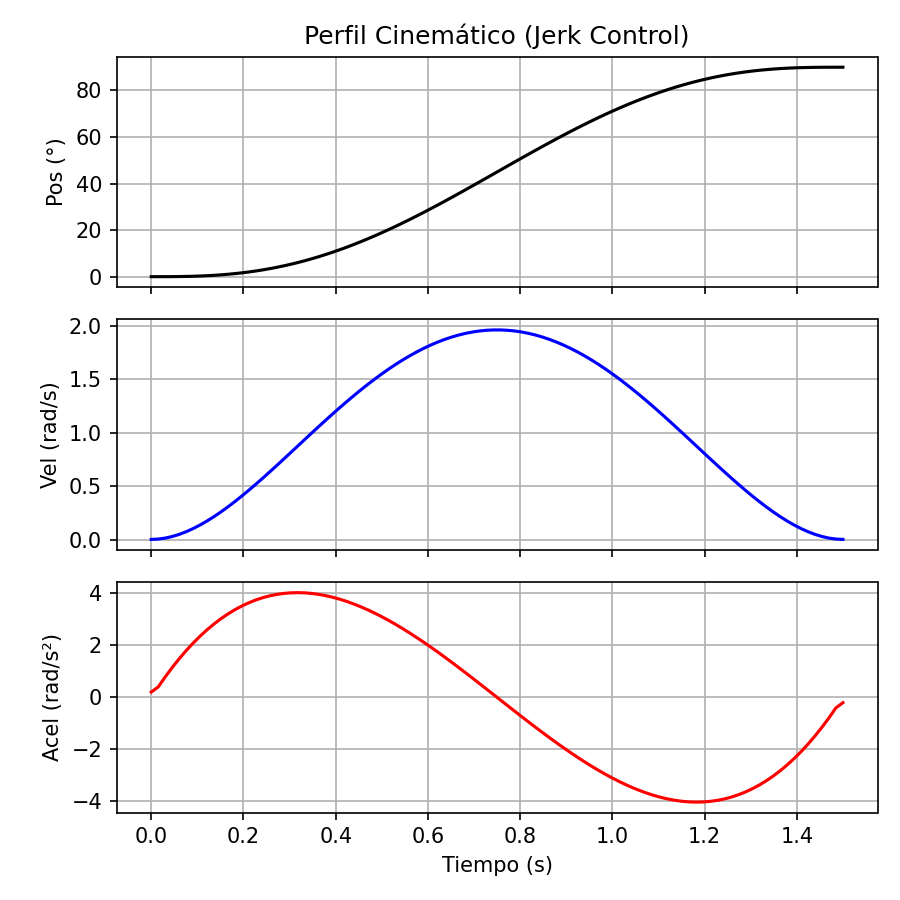
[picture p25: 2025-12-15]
Robot SCARA/2_control.png

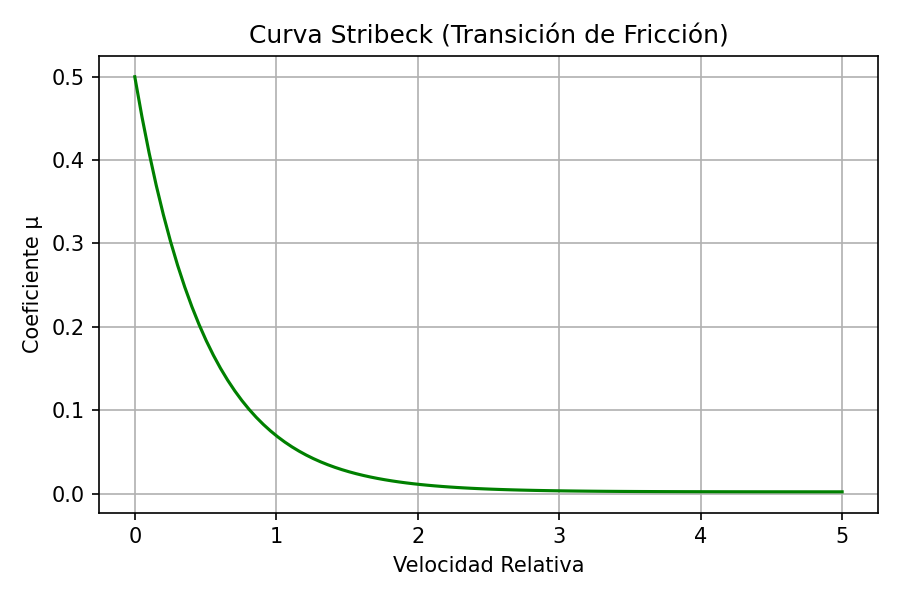
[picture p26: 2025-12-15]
Robot SCARA/5_tribologia.png

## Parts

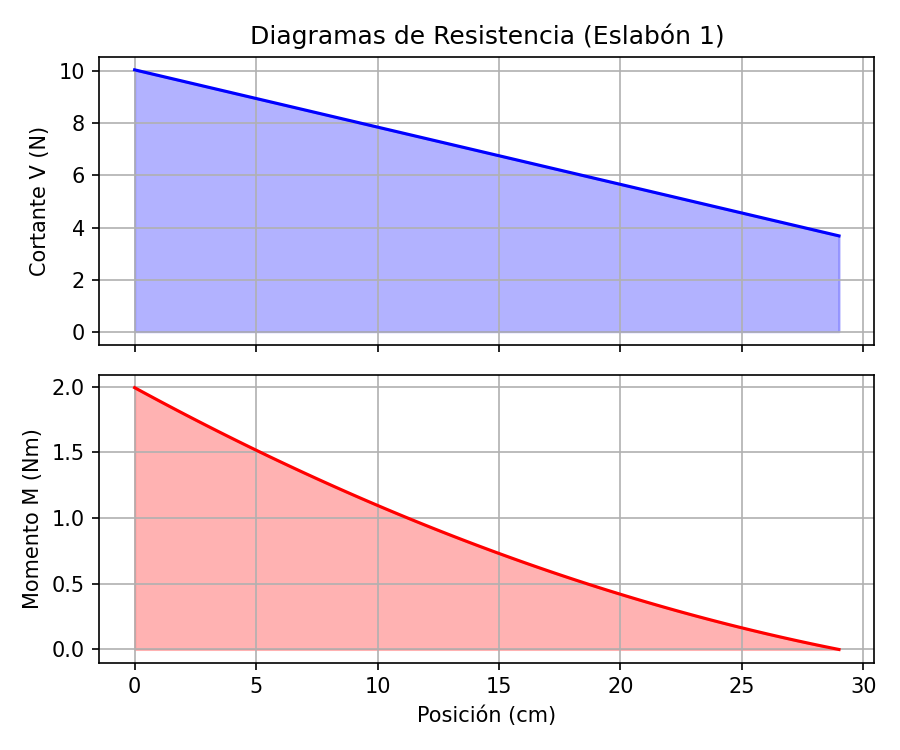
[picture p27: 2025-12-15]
Robot SCARA/4_materiales.png

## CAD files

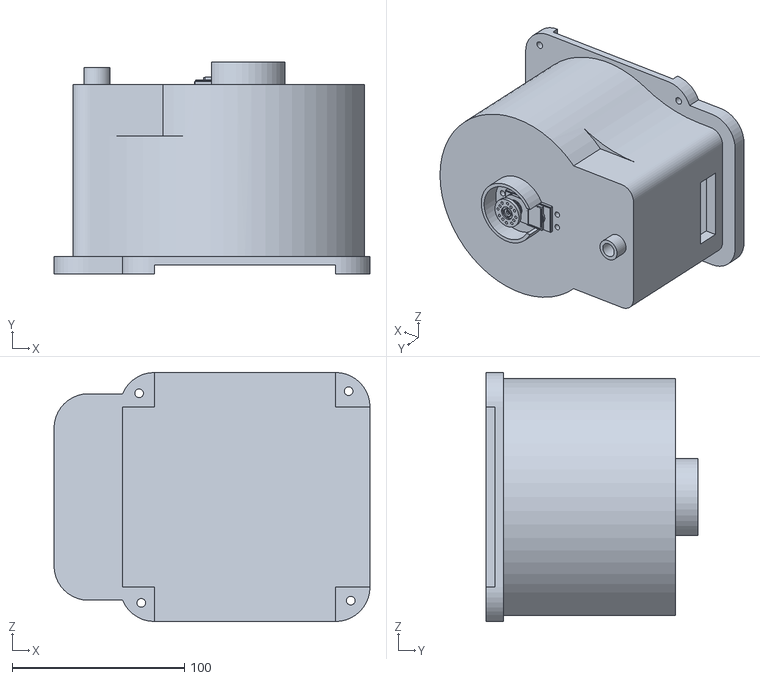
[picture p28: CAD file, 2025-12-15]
Robot SCARA/static/models/SCARA Base.STL
183.6 x 123.0 x 144.7

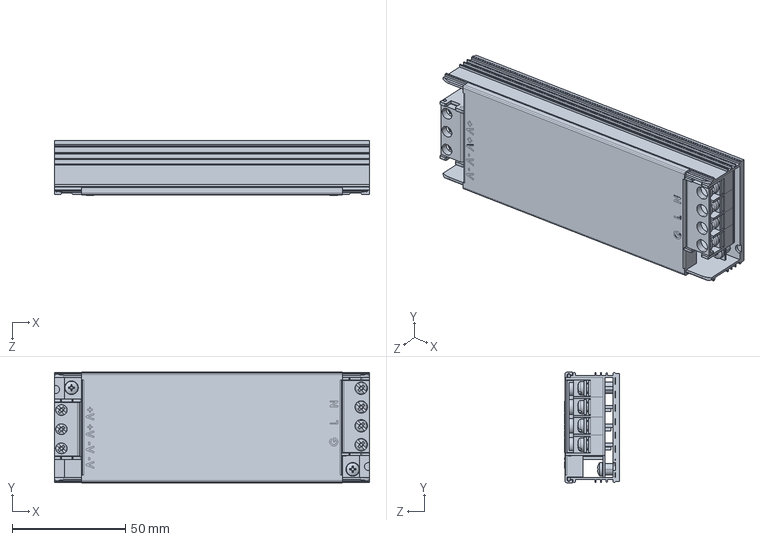
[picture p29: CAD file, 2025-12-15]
SCARA Diseño/PS 12VDC 8.3A Model DT-NT12V-100W.SLDPRT
139.0 x 48.9 x 24.1 mm

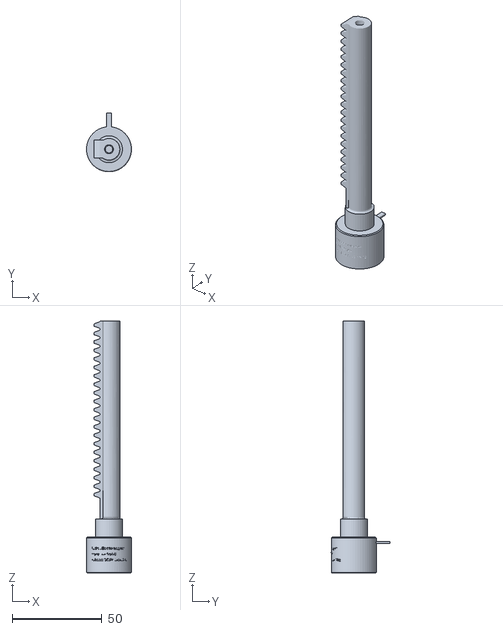
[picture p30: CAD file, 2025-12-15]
Robot SCARA/static/models/ESLABONFINAL.STL
25.0 x 32.5 x 140.0

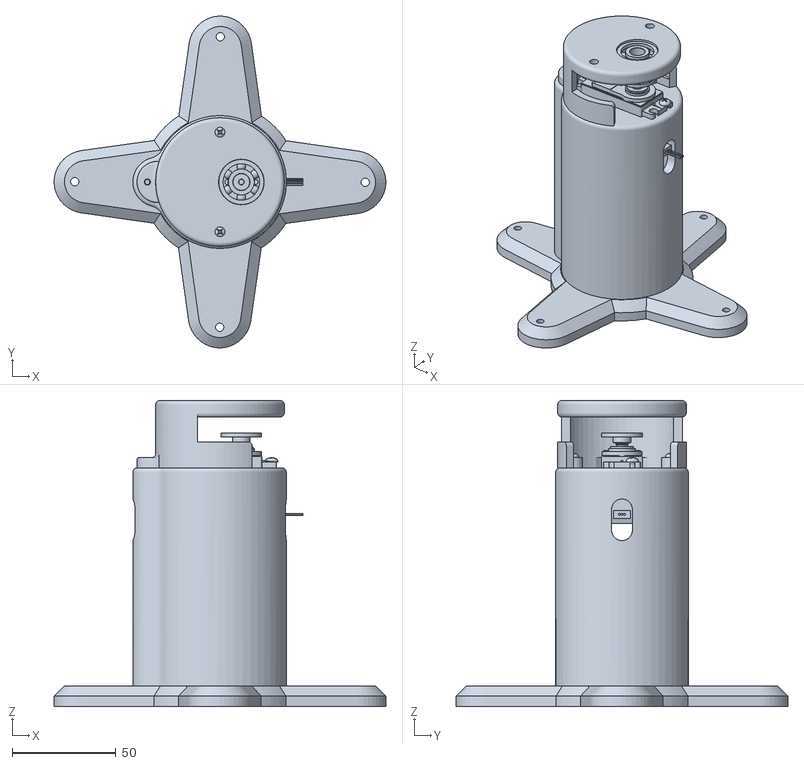
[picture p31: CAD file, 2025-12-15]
Robot SCARA/static/models/BASE.STL
160.0 x 160.0 x 147.5

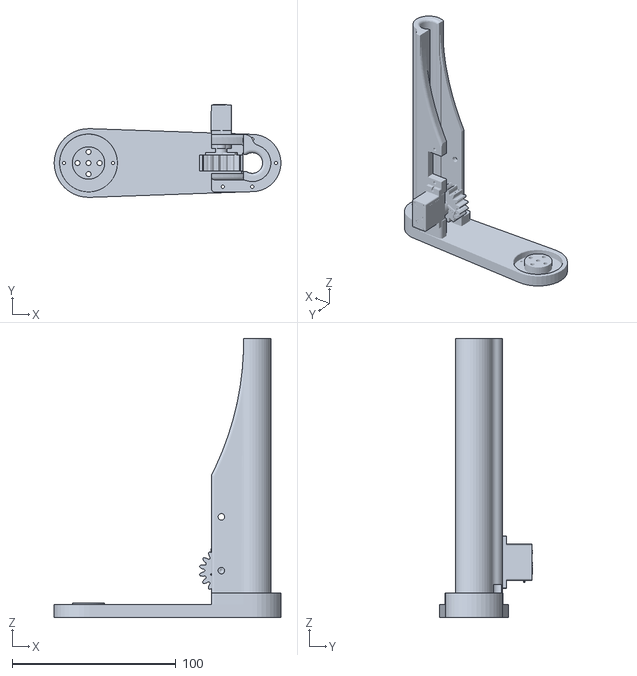
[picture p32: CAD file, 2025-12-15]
Robot SCARA/static/models/ESLABON123.STL
138.4 x 56.6 x 170.4

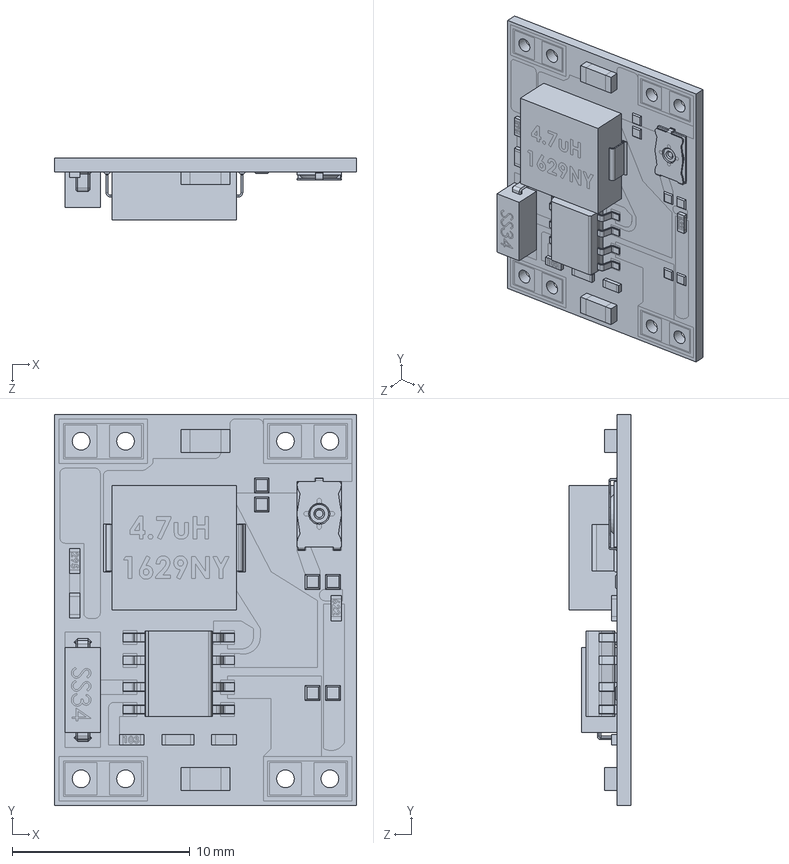
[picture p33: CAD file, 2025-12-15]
SCARA Diseño/MP1584.SLDPRT
17.0 x 22.0 x 3.50 mm

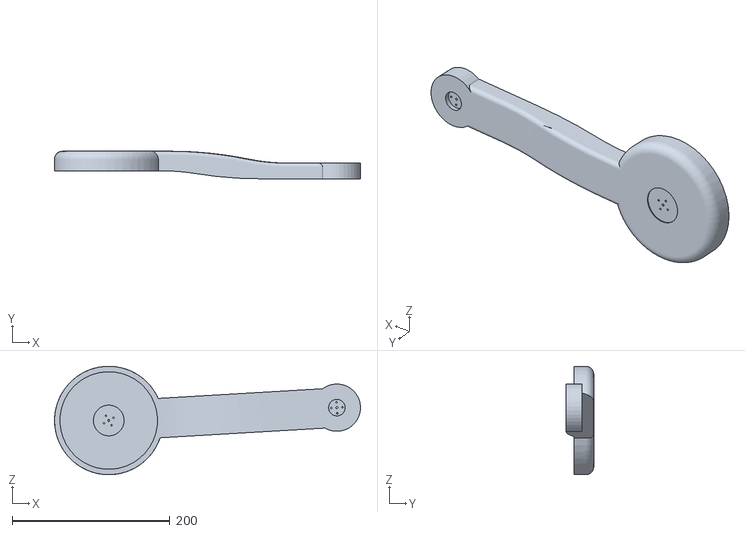
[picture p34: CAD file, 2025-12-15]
Robot SCARA/static/models/SCARA Eslabon 1.STL
388.1 x 35.0 x 137.5

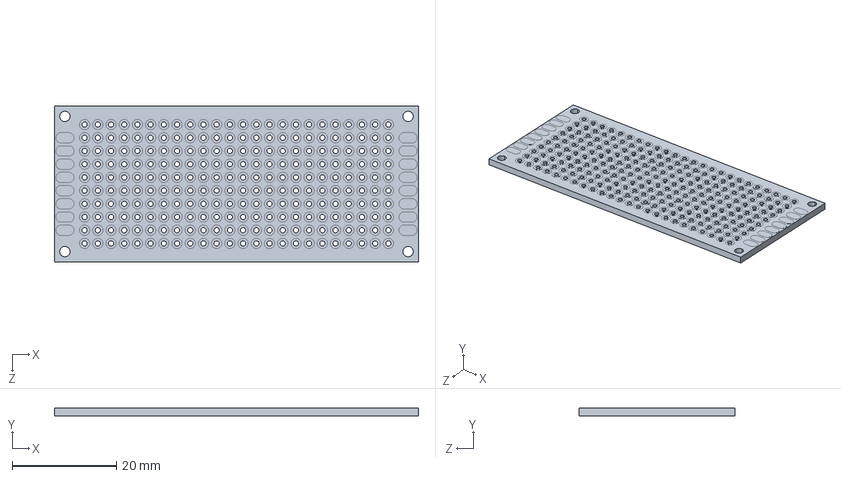
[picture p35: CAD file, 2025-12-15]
SCARA Diseño/PCB Perforada 3x7cm.SLDPRT
70.0 x 1.55 x 30.0 mm

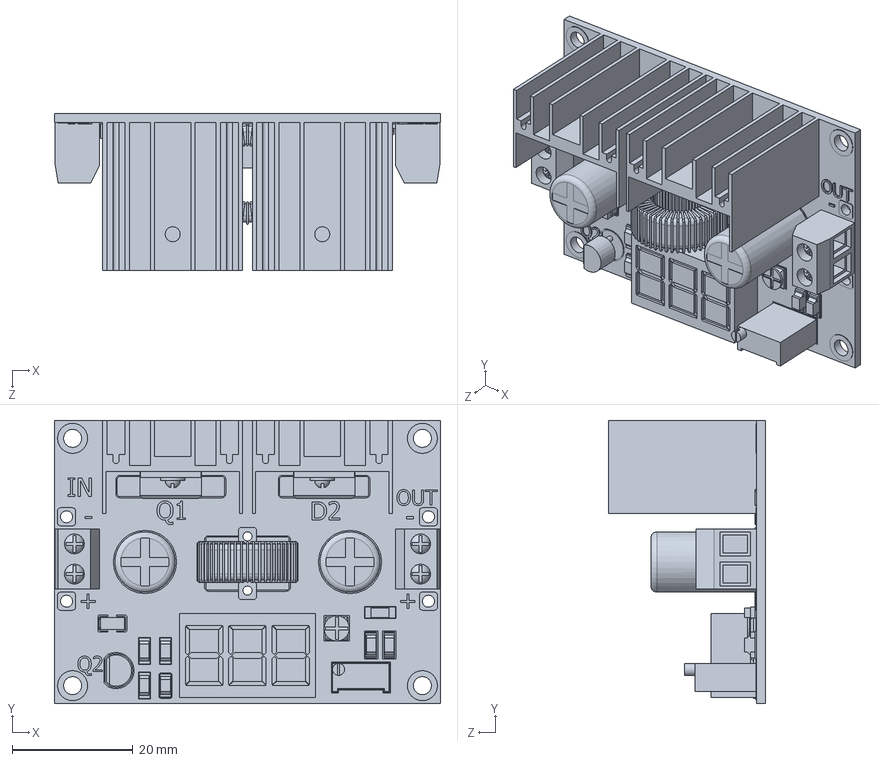
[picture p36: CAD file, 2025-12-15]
SCARA Diseño/XL4016.SLDPRT
64.0 x 47.0 x 26.0 mm

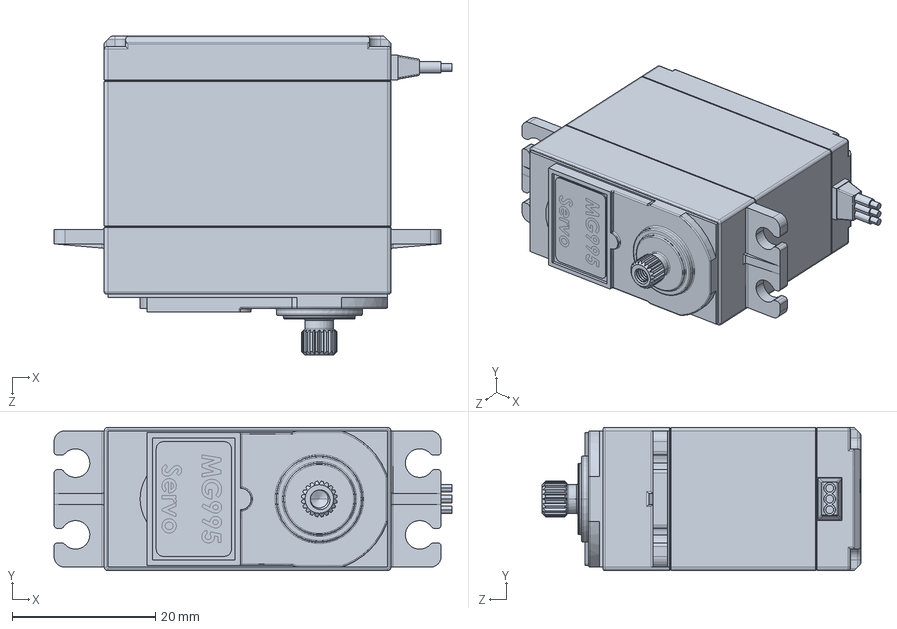
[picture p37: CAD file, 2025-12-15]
SCARA Diseño/MG995.SLDPRT
55.5 x 20.0 x 44.5 mm

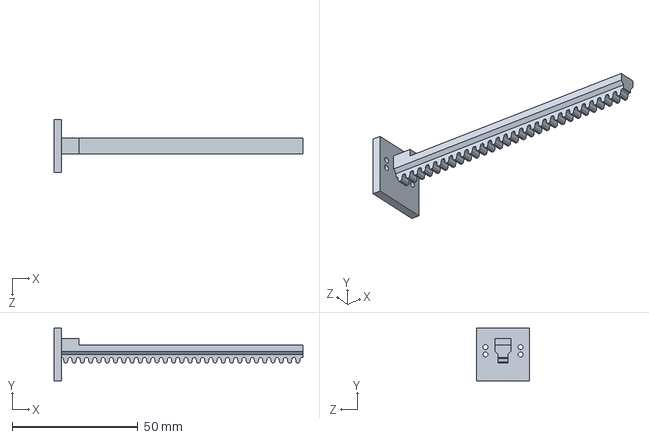
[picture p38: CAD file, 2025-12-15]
SCARA Diseño/Cremallera chida.SLDPRT
99.2 x 21.0 x 21.0 mm

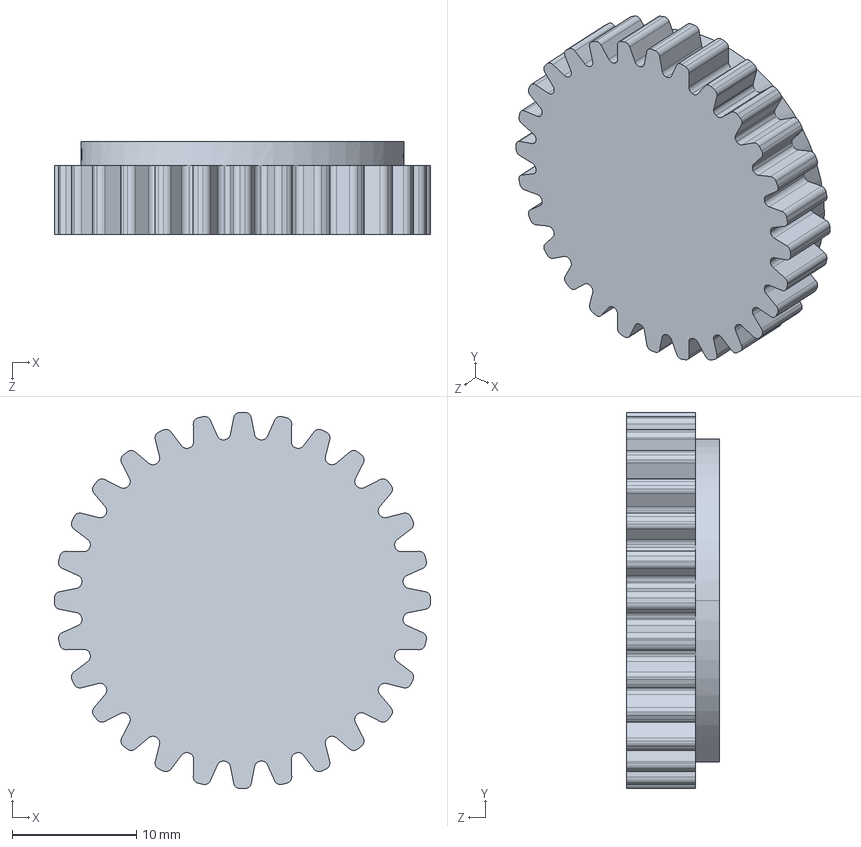
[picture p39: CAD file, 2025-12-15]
SCARA Diseño/Engrane.SLDPRT
30.2 x 30.2 x 7.51 mm

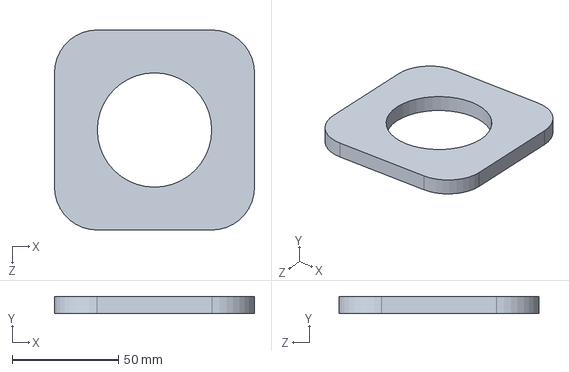
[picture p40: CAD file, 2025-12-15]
SCARA Diseño/rodamiento.SLDPRT
94.0 x 8.17 x 94.0 mm

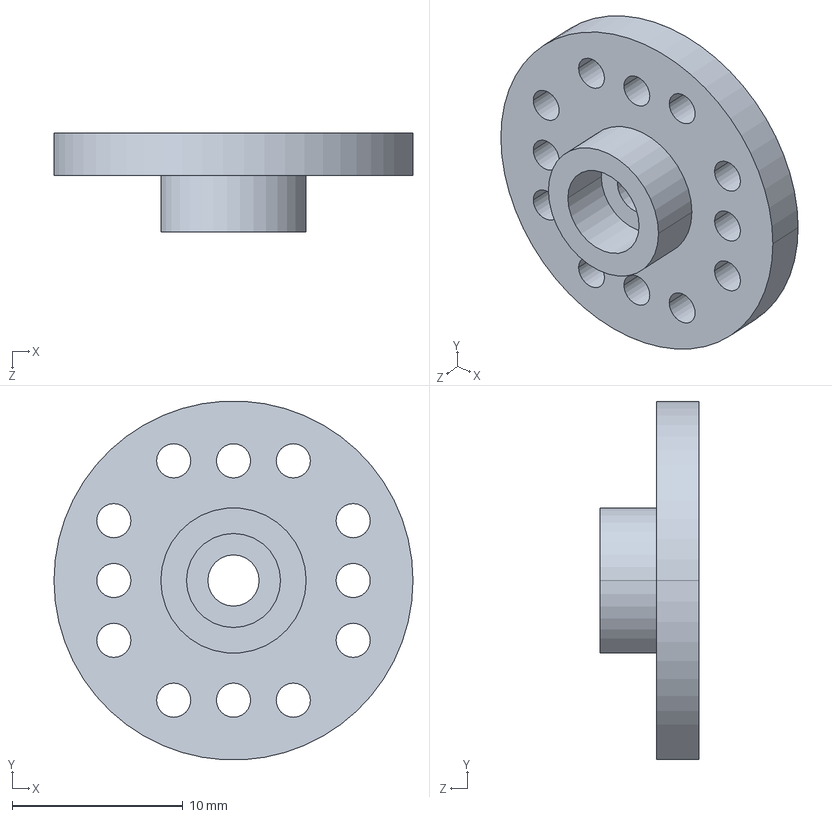
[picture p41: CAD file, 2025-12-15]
SCARA Diseño/Rueda Servomotor.SLDPRT
21.0 x 21.0 x 5.80 mm

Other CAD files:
SCARA Diseño/Headers Hembra.SLDASM
SCARA Diseño/ESP32-C3.SLDASM
SCARA Diseño/Headers Macho.SLDASM
SCARA Diseño/Final Assembly.SLDASM
SCARA Diseño/Base 1.SLDPRT
SCARA Diseño/Base 2.SLDPRT
SCARA Diseño/Base 3.SLDPRT
SCARA Diseño/Base 4.SLDPRT
SCARA Diseño/Base pedorra.SLDPRT
SCARA Diseño/Base.SLDPRT
SCARA Diseño/Body.SLDPRT
SCARA Diseño/Cubo 1.SLDPRT
SCARA Diseño/Cubo 2.SLDPRT
SCARA Diseño/Cubo 3.SLDPRT
SCARA Diseño/Enchufe.SLDPRT
SCARA Diseño/Eslabon 2.SLDPRT
SCARA Diseño/Eslabón 1.SLDPRT
SCARA Diseño/Gear 1.SLDPRT
SCARA Diseño/Gear 2.SLDPRT
SCARA Diseño/Gripper.SLDPRT
SCARA Diseño/Linkage.SLDPRT
SCARA Diseño/Motor Gear.SLDPRT
SCARA Diseño/Part4.SLDPRT
SCARA Diseño/Part9 - Gear 4.SLDPRT
SCARA Diseño/Pin.SLDPRT
SCARA Diseño/Soporte del actuador lineal.SLDPRT
SCARA Diseño/Tapa Base.SLDPRT
SCARA Diseño/Tapa Eslabon 2.SLDPRT
SCARA Diseño/Tapa final.SLDPRT
SCARA Diseño/Tapita.SLDPRT
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

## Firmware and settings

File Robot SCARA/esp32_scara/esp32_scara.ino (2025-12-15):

#include <WiFi.h>
#include <WiFiUdp.h>
#include <ESP32Servo.h>

// --- 1. CONFIGURACIÓN DE RED ---
const char* ssid = "Redmi Note 13";   // INFINITUM86C2
const char* password = "22072207";   // ELd4TfVbHW

WiFiUDP udp;
unsigned int localPort = 4210;       // Puerto donde escucha el ESP32
unsigned int serverPort = 5005;      // Puerto donde escucha Python
char packetBuffer[255];

IPAddress serverIP;                  // Se llena automáticamente al recibir datos
bool connectionEstablished = false;  // Bandera para saber si ya nos hablaron

// Timer para el Heartbeat
unsigned long lastHeartbeat = 0;
const long heartbeatInterval = 1000; // Enviar ping cada 1 segundo

// --- 2. DEFINICIÓN DE OBJETOS SERVO ---
Servo servoBase;    
Servo servoCodo;    
Servo servoZ;        
Servo servoGripper;  

// --- 3. PINES REALES ---
#define PIN_BASE 5
#define PIN_CODO 4
#define PIN_Z    3
#define PIN_GRIP 2

// --- 4. CALIBRACIÓN ---
int offset_base = 85; 
int offset_codo = 90; 

const int ANGULO_ABIERTO = 20; 
const int ANGULO_CERRADO = 74; 

void moverRobot(float q1, float q2, float z, int grip);

void setup() {
  Serial.begin(115200);

  // Configuración de Servos
  servoBase.setPeriodHertz(50); servoBase.attach(PIN_BASE, 500, 2500);
  servoCodo.setPeriodHertz(50); servoCodo.attach(PIN_CODO, 500, 2500);
  servoZ.setPeriodHertz(50);    servoZ.attach(PIN_Z, 500, 2500);
  servoGripper.setPeriodHertz(50); servoGripper.attach(PIN_GRIP, 500, 2500);

  // Posición Inicial Segura
  servoBase.write(offset_base);
  servoCodo.write(offset_codo);
  servoZ.write(0);       
  servoGripper.write(ANGULO_ABIERTO);

  // Conexión WiFi
  Serial.print("Conectando a WiFi: ");
  Serial.println(ssid);
  
  // Aseguramos modo estación (Cliente)
  WiFi.mode(WIFI_STA); 
  WiFi.begin(ssid, password);
  
  while (WiFi.status() != WL_CONNECTED) {
    delay(500);
    Serial.print(".");
  }

  // --- ¡ESTO FALTABA! ---
  // Desactiva el ahorro de energía para que el WiFi nunca se duerma.
  // Crucial para movimiento fluido en tiempo real.
  WiFi.setSleep(false); 
  
  Serial.println("\n--- CONECTADO ---");
  Serial.print("IP del Robot: ");
  Serial.println(WiFi.localIP()); 
  
  udp.begin(localPort);
  Serial.println("Esperando primer comando para sincronizar IP del servidor...");
}

void loop() {
  // 1. RECEPCIÓN DE COMANDOS
  int packetSize = udp.parsePacket();
  
  if (packetSize) {
    // Autodescubrimiento del servidor
    if (!connectionEstablished) {
        serverIP = udp.remoteIP();
        connectionEstablished = true;
        Serial.print("✅ Servidor detectado en: ");
        Serial.println(serverIP);
    }
    // Actualizar si la IP cambia
    if (udp.remoteIP() != serverIP) {
        serverIP = udp.remoteIP();
    }

    int len = udp.read(packetBuffer, 255);
    if (len > 0) packetBuffer[len] = 0;
    
    float q1, q2, z;
    int grip;
    int n = sscanf(packetBuffer, "%f,%f,%f,%d", &q1, &q2, &z, &grip);
    
    if (n == 4) {
        moverRobot(q1, q2, z, grip);
    }
  }

  // 2. HEARTBEAT (PING CONSTANTE)
  unsigned long currentMillis = millis();
  if (connectionEstablished && (currentMillis - lastHeartbeat >= heartbeatInterval)) {
    lastHeartbeat = currentMillis;
    
    udp.beginPacket(serverIP, serverPort);
    udp.write((const uint8_t*)"PING", 4);
    udp.endPacket();
  }
}

void moverRobot(float q1, float q2, float z, int grip) {
  int angulo_base_servo = constrain(offset_base + q1, 0, 180);
  int angulo_codo_servo = constrain(offset_codo + q2, 0, 180);
  int angulo_z_servo = map(z * 10, 0, 55, 0, 180); 
  angulo_z_servo = constrain(angulo_z_servo, 0, 180);

  servoBase.write(angulo_base_servo);
  servoCodo.write(angulo_codo_servo);
  servoZ.write(angulo_z_servo);
  
  if (grip == 1) servoGripper.write(ANGULO_CERRADO); 
  else servoGripper.write(ANGULO_ABIERTO); 
}
